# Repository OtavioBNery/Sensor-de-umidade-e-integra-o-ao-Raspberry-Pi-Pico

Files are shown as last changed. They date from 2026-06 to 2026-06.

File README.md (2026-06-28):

# Sensor-de-umidade-e-integração-ao-Raspberry-Pi-Pico
# Membros do projeto
Filipe Tadeu Chudo Sepican – 23.00563-3

Gabriela de Castro Oliveira Szwif – 23.00868-7

Otávio Biadola Nery – 23. 01584-5

João Luiz Du Plessis Lang – 22.00263-4

# Objetivo do projeto
Desenvolvimento de um sistema composto por um sensor desenvolvido pelos integrantes e pelo microcontrolador Raspberry Pi Pico que atenda ao tema de sustentabilidade, sendo escolhido trabalhar com o desenvolvimento de um sensor capacitivo de umidade do solo

# Descrição do sistema
Como pode ser visto no diagrama de blocos abaixo, o sistema consiste na leitura do valor obtido pelo sensor, sua exibição no LCD 16x2, e uma comparação com o valor da umidade percentual definida pelo usuario, de modo a gerar um controle por histerse para que atinja o valor de alvo por meio de uma lâmpada incandescente
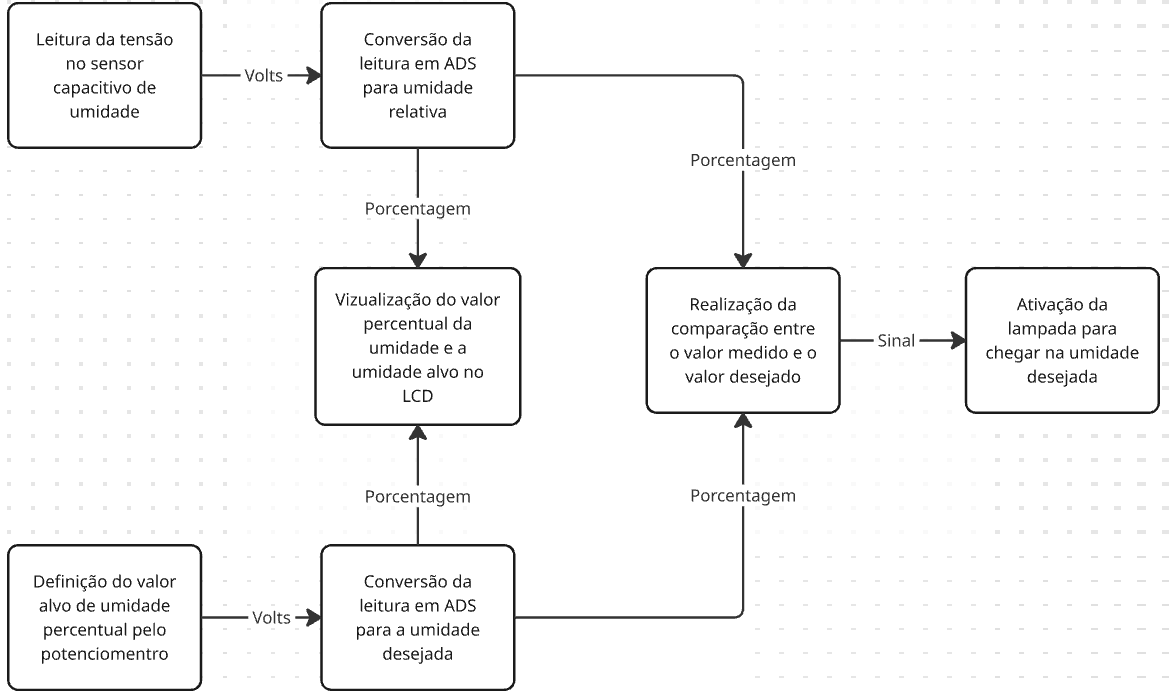
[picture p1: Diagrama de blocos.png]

<hr>

# Localização de arquivos importantes
Os arquivos de PCB, CAD, codigo do microcontrolador, apresentação do projeto e relátorio detalhado sobre o desenvolvimento da aplicação podem ser obtidos na pasta Projeto

# Sensor finalizado
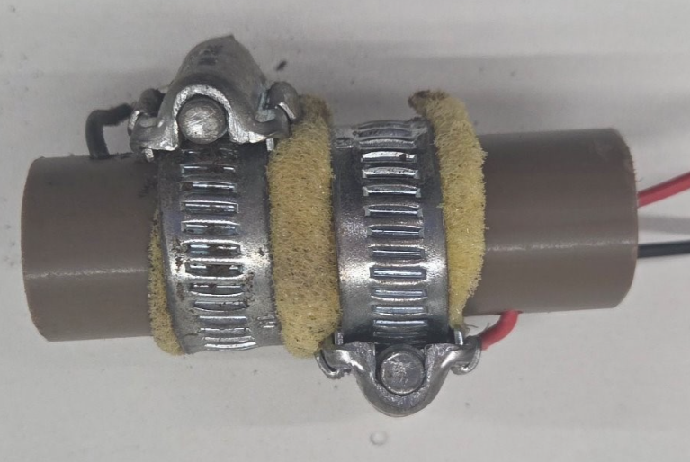
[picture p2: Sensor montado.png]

<hr>
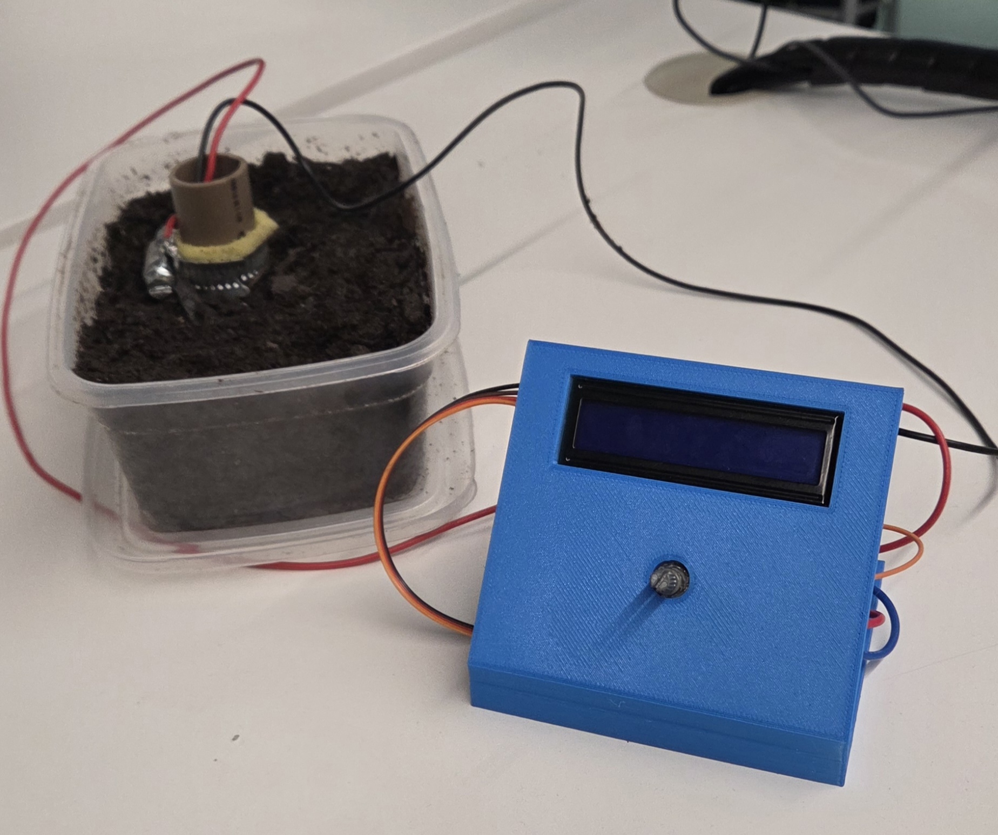
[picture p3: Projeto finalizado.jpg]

<hr>

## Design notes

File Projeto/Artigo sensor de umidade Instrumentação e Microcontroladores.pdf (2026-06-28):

Relatório do projeto semestral interdisciplinar de Instrumentação e Sistemas Microcontrolados PROJETO DA MAUÁ 2026

Filipe Tadeu Chudo Sepican 1

; Gabriela de Castro Oliveira Szwif ¹

; Otávio Biadola Nery 1
; João Luiz
Du Plessis Lang 1

; Andressa Martins 2

; Rodrigo França 2

1 Aluno(a) do Instituto Mauá de Tecnologia (IMT);
2 Professor(a) do Instituto Mauá de Tecnologia (IMT).

Resumo. O projeto consiste na confecção de um sensor capacitivo de umidade do solo integrado a um Raspberry PI Pico assim como a programação do código envolvido na leitura dos dados enviados pelo sensor, interpretação dos dados e exibição em uma tela LCD e acionamento de um relé conectado a uma lâmpada incandescente quando a umidade alvo configurada pelo usuário for atingida.

Introdução

No primeiro semestre de 2026, foi proposto um projeto integrado entre as disciplinas

Instrumentação e Microcontroladores e Sistemas Microcontrolados com o objetivo de

“[...] desenvolver competências práticas em Engenharia de Controle e Automação por meio do projeto e implementação de um sistema embarcado baseado em um sensor analógico integrado a um microcontrolados RP2040. O projeto envolve a aquisição e o condicionamento de sinais, processamento de dados, implementação de lógica de controle, comunicação e exibição de informações, além do acionamento de atuadores, aplicados a problemas reais nas áreas de saúde, automação industrial, sustentabilidade ou automação residencial.” (MARTINS; FRANÇA, 2026).

Assim, o grupo escolheu desenvolver um sensor de umidade percentual do solo, dentro do

tema de sustentabilidade. Segundo o Trabalho de Conclusão de Curso de Gustavo Neias Ribeiro

Vieira (2023), "A gestão eficiente da umidade do solo e a conservação deste recurso essencial

representam pilares fundamentais para o desenvolvimento agrícola sustentável.".

Vieira afirma, ainda, que "a agricultura necessita constantemente evoluir para atender às

demandas em constante mudança" (VIEIRA, 2023) e que o avanço tecnológico e científico "se tornou

um pilar fundamental para impulsionar a produtividade agrícola e enfrentar os desafios impostos pelas

mudanças climáticas" (VIEIRA, 2023). Ademais, o autor destaca que, dentre tais desafios, um de

grande importância é a escassez de recursos hídricos utilizáveis. Logo, o desenvolvimento de

tecnologias que tornem possível uma utilização responsável e eficiente da água é algo de extrema

importância.

Para mais, além de auxiliar na mitigação dos impactos ambientais do plantio agrícola, o

monitoramento da umidade do solo também incute em um aumento da produtividade do mesmo.

"A umidade do solo, ao influenciar o teor de ar presente, a

salinidade e a concentração de substâncias tóxicas,

desempenha um papel profundo e abrangente. Além disso, ela

está intrinsecamente conectada à estrutura do solo, à sua

espessura e à sua estabilidade. Mesmo a temperatura do solo e

sua capacidade de reter calor são impactadas pelo nível de

umidade." (VIEIRA, 2023).

Desse modo, torna-se possível adotar estratégias de otimização da produtividade a partir do

ajuste da humidade do solo. Assim, um sensor de humidade "[...] possibilita o acompanhamento em

tempo real das condições do solo, evitando desperdícios e promovendo práticas agrícolas mais

sustentáveis." (BALEEIRO et al., 2025).

Material e Métodos

Confecção do sensor

Devido as limitações propostas para o desenvolvimento do projeto, sendo primordialmente a

elaboração da aplicação sem o uso de um sensor comercial, foi decidido trabalhar com o sensor

capacitivo de umidade proposto por Barros (2020) (Figura 1) devido sua facilidade e simplicidade de

montagem e aplicação, tornando assim o projeto de fácil reprodução e com resultados consistentes.

Figura 1 – Sensor de umidade desenvolvido por Barros

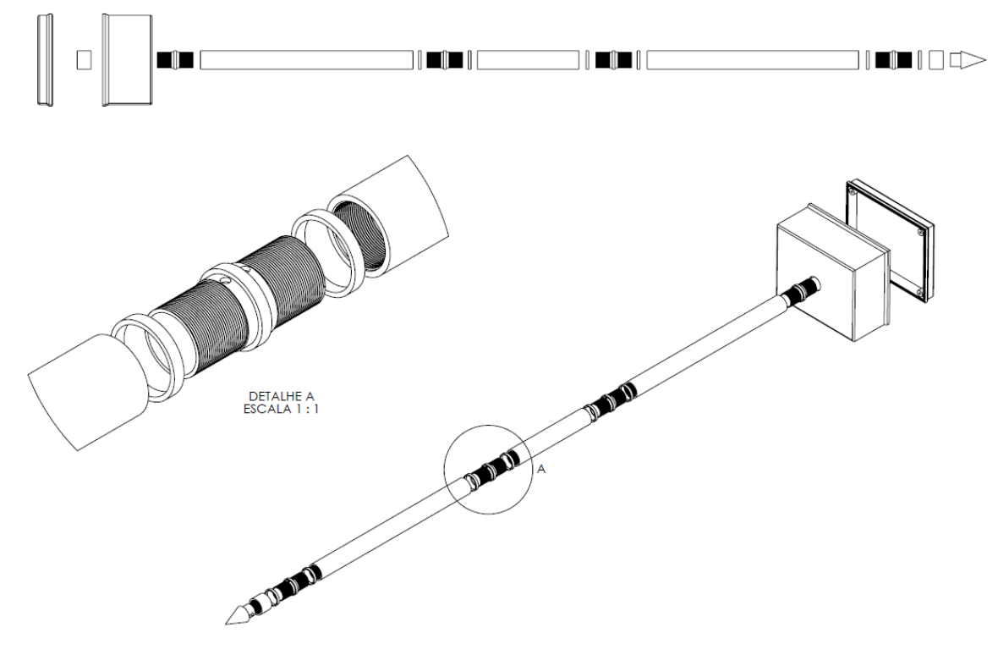
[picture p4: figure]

Fonte: Barros (2020)

Como descrito por Barros (2020, p.2), "Esse sensor consiste em duas placas paralelas feitas

de material condutor e entre elas há um material isolante chamado de dielétrico", portanto, para o

metal condutor foi escolhido trabalhar com abraçadeiras de aço inox (Figura 2) devido sua resistência

a corrosão natural, relevante considerando o ambiente em que o sensor seria instalado, e alta

resistência mecânica, garantindo assim um sensor durável ao longo prazo. Para o material dielétrico,

foi utilizado uma esponja comum de limpeza (Figura 3) devido à sua alta permeabilidade e à fácil

disponibilidade no mercado, tornando-se, assim, um projeto de fácil reprodução e mantendo um baixo

custo. Por fim, para o corpo do sensor foi selecionado um cano PVC marrom, resistente a condições

ambientais.

Figuras 2, 3 – Materiais utilizados para a confecção do sensor

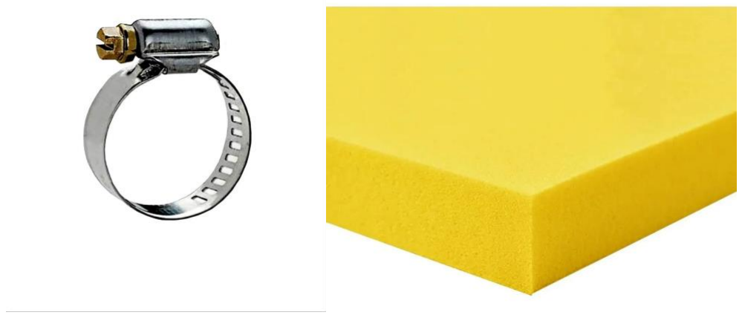
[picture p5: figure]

Fonte: Os autores

Seguindo como descrito por Barros (2020), o sensor foi desenvolvido de modo em que o

elemento dielétrico esteja em contato direto com o meio que se deseja medir, como pode ser visto na

Figura 4.

Figura 4 – Sensor de umidade finalizado

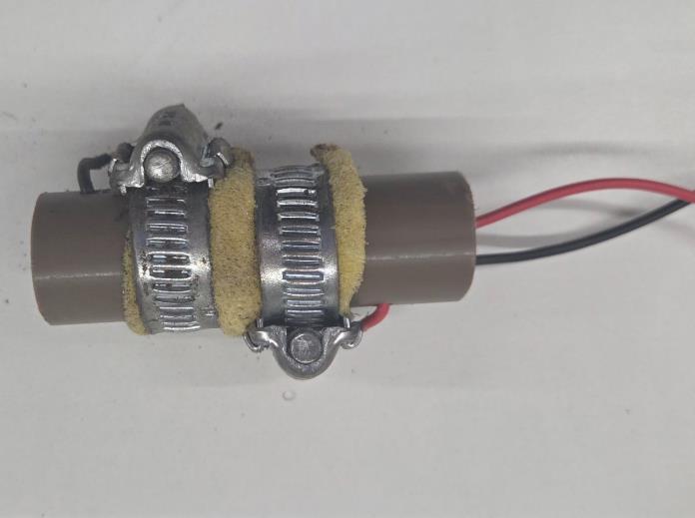
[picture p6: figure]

Fonte: Os autores

Calibração do sensor

A calibração foi feita através da determinação das tensões obtidas de dados levantados em um

ambiente controlado. Primeiramente, o sensor foi colocado em um container contendo terra seca, após

a leitura inicial, um valor inicial da carga no capacitor foi enviado ao Raspberry Pi Pico e este tornou-

se nosso valor inicial de carga nomeada “umidade do sensor em 0%”.

Após obtermos a “umidade do sensor em 0%”, água foi adicionada em steps de 5mL à terra

do container então, pulsos elétricos no intervalo de 5ms foram emitidos pelo Raspberry Pi Pico e,

com a estabilização dos valores enviados, novos pontos de umidade foram anotados. Novas medições

foram realizadas até a saturação do sensor em 35mL ser atingida.

A obtenção destes valores foi possível devido ao fato que à adição da água ao material

dielétrico muda suas propriedades capacitivas, de modo que quanto maior a quantidade de água

absorvida pelo material, menor seria seu tempo de carga completa, aumentando assim gradativamente

os valores de carga a cada adição de água no sistema até que seja atingido o valor de saturação.

Tabela 1 – Valores experimentais do ADS em relação a água inserida (mL)

Água inserida (mL) ADS
0
5 | 2500
| 2630
10 | 2810
15 | 3000
20 | 3170
25
30
35 | 3415
| 3680
| 3930

Com os valores determinados, uma equação correspondente a umidade do sensor foi traçada

e adotada para interpolação dos valores de leitura percentuais.

Projeto elétrico

Para a leitura do sinal analógico do sensor, utilizamos o microcontrolador Raspberry PI Pico,

ele foi escolhido devido ao conversor analógico para digital, ADS, já embutido no microcontrolador,

diminuindo assim a complexidade elétrica do projeto. Para a visualização e resposta do sistema, foi

empregado um display LCD 16x2 e uma lâmpada incandescente, a qual por meio de um circuito de

relé, permite um simples controle por histerese da umidade máxima desejada no sistema, sendo ela

definida pelo usuário através do uso de um potenciômetro.

Figura 6 – Esquema elétrico para leitura e resposta do sistema

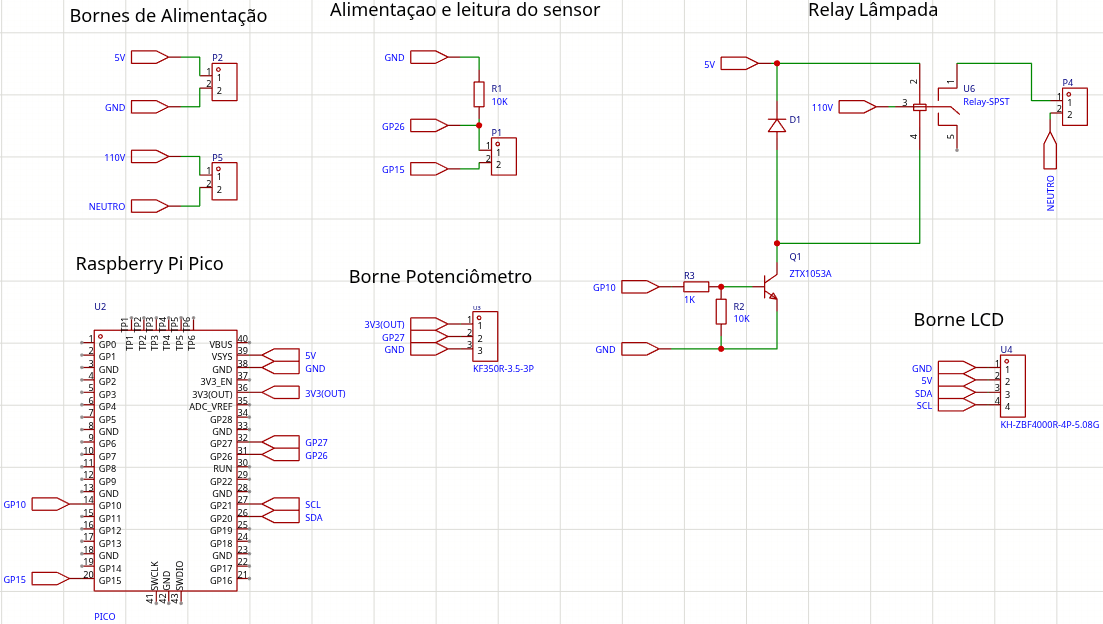
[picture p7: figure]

Fonte: Os autores

Código utilizado

Para o desenvolvimento do projeto foi utilizado programação em linguagem C devido a sua

alta velocidade e eficiência na execução dos comandos necessários. Durante a etapa da programação

do microcontrolador foram levados em consideração diversos conceitos fundamentalmente

importantes para o funcionamento adequado do sistema, dentre eles, vale se destacar: o tempo

escolhido para a carga do capacitor; a implementação de um filtro digital dos valores recebidos do

sensor; a integração da equação obtida durante o processo de calibração para converter corretamente

os valores recebidos no pino de ADS para umidade percentual; o uso de histerese para o controle do

sensor; e pôr fim a adoção de um sistema não bloqueante.

O diagrama de blocos a seguir demonstra o comportamento desejado do sistema composto

pelo sensor e o microcontrolador.

Figura 7 – Diagrama de blocos do funcionamento do sistema

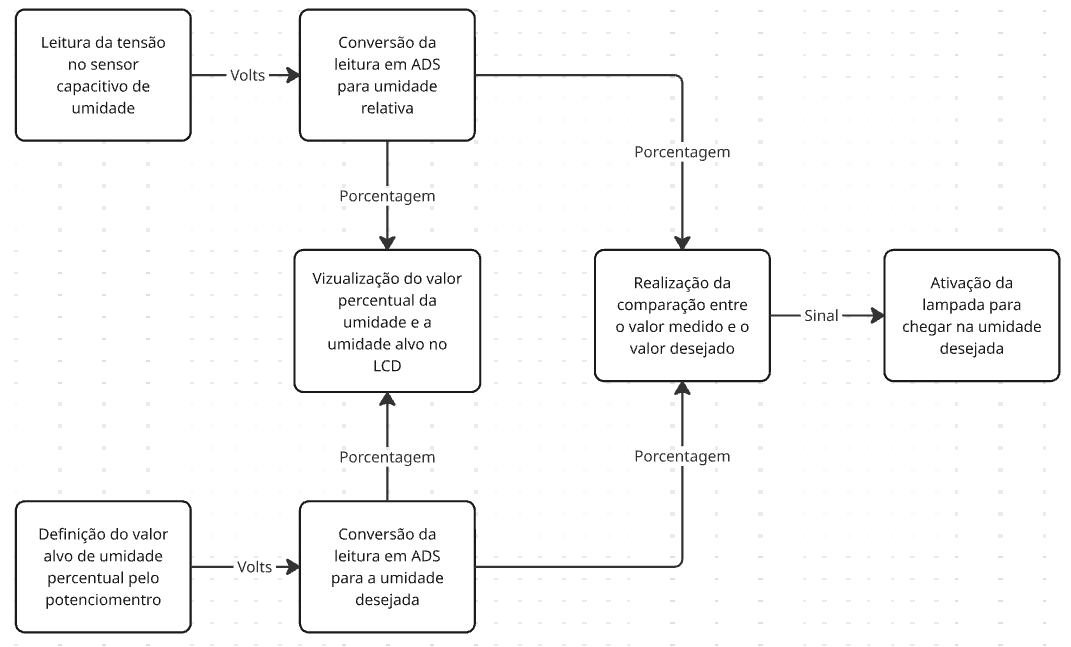
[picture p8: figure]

Fonte: Os autores
Como pode ser visto na Figura 8, há a parte do código responsável pelo tempo de carga de

1ms e a efetuação de um intervalo de 5ms entre as medidas, a qual tem o intuito de evitar uma situação

de eletrolise que danificaria as partes metálicas do sensor com o passar do tempo.

Figura 8 – Segmento do código referente ao tempo de carga e intervalo

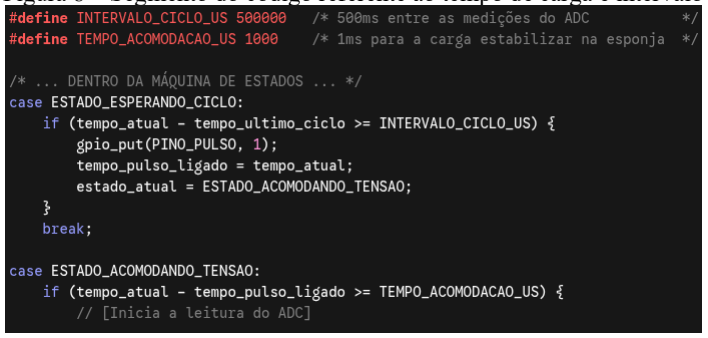
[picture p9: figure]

Fonte: Os autores
Com a intenção de diminuir o ruido no sistema, foi implementado um filtro totalmente digital,

o qual usará como entrada um conjunto de 20 medições realizadas pelo sensor antes de mudar

ativamente o valor no LCD, como pode ser visto na Figura 9.

Figura 9 – Segmento do código referente ao filtro digital utilizado

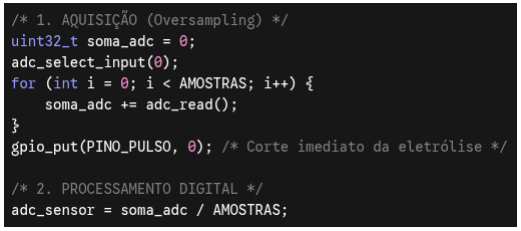
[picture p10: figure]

Fonte: Os autores
Para a realizar o controle por histerese, foi pensado que o sistema responderia à valores acima

de 5% do definido pelo usuário, evitando assim estresse desnecessário no circuito do relé e na

lâmpada incandescente.

Figura 10 – Segmento do código referente ao controle por histerese

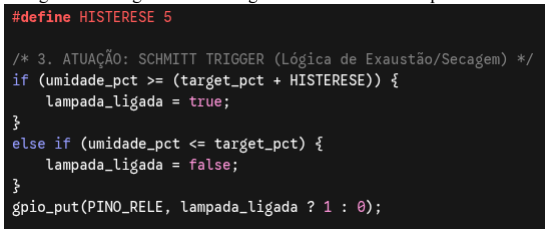
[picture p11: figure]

Fonte: Os autores
Por fim foi feita a implementação da equação de relação entre a medida ADS realizada pelo

sensor e a umidade percentual obtida durante a etapa de calibração, a fim de realizar a visualização

pelo display LCD e a comparação com o valor definido pelo usuário.

Figura 11– Segmento do código referente à implementação da equação da umidade percentual

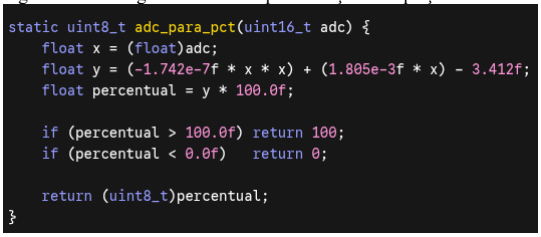
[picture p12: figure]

Fonte: Os autores

Estrutura Mecânica

Para o acomodamento do display LCD, do potenciômetro e do Raspberry PI Pico uma

estrutura em PLA foi impressa após seu modelamento em CAD (Figura 12). Na plataforma superior o LCD foi fixado através de um encaixe e o potenciômetro foi colado ao recorte projetado para seu

encaixe. O Raspberry foi acoplado a base da estrutura onde um recorte foi deixado para sua fixação.

Figura 12 – Projeto CAD da base

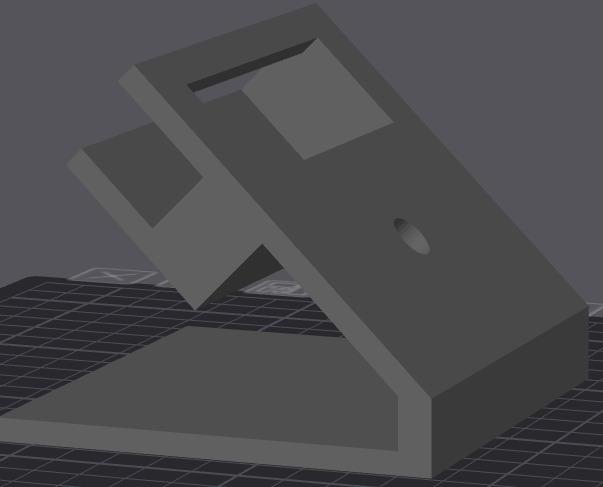
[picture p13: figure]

Fonte: Os autores

Figura 13 – Estrutura mecânica finalizada

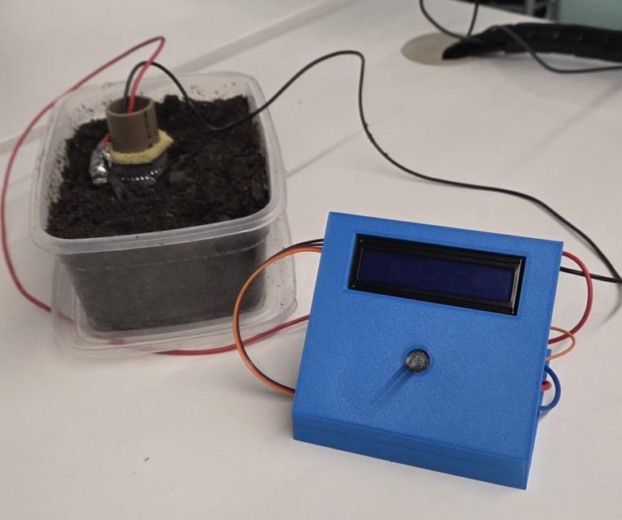
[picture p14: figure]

Fonte: Os autores

Resultados e Discussão

O sensor demonstrou alta precisão na leitura de valores da sua umidade demonstrando assim

uma curva de carga bem determinada (Figura 14). O código teve seu funcionamento ideal, não demonstrando nenhuma inconsistência e gerando a exibição correta no LCD, assim como a histerese

programada e o envio do sinal de acionamento ao relé corretamente.

Figura 14 – Curva de carga do sensor

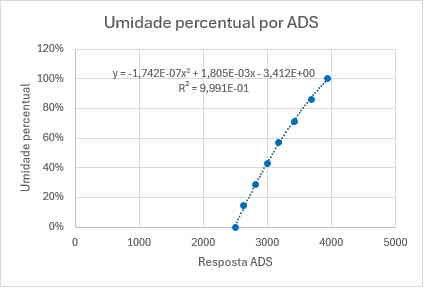
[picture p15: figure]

Fonte: Os autores

Após a conclusão do projeto certos pontos de melhora foram identificados para melhor

implementação do sensor. Primeiramente um melhor isolamento dos pontos de medida deve ser

aplicado, através de resina ou outro material isolante, tal mudança deve-se pelo fato da terra em si ser

condutiva. Em segundo lugar, o dimensionamento do resistor R1 afetou diretamente a porção

utilizada da curva do capacitor gerado pelo sensor assim, tornando-a menor e menos representativa

da umidade real. Um outro valor de resistência teria deslocado a curva suficientemente para se mostrar

mais indicativa da umidade real do ambiente e não apenas a umidade local do sensor.

No âmbito da confecção da PCB em si também houve uma falha no momento de solda do relé

e, portanto, ele não era ativado. Isso deveria ser evitado através da uma solda mais cuidadosa ou uma

PCB montada com trilhas maiores.

Conclusões

O projeto cumpriu o objetivo proposto de desenvolver as competências tanto na disciplina de

Instrumentação quanto em Sistemas Microcontrolados por meio do desenvolvimento de um sistema

embarcado para o monitoramento da umidade do solo e da integração a um sistema comandado pelo

microcontrolador RP2040. A escolha de materiais simples, como braçadeiras inox, cano PVC e

esponja comum se mostram adequadas, resultando em um sensor de baixo custo e razoavelmente

resistente as condições do ambiente de instalação, tornando assim os resultados consistentes e

previsíveis.

Como apontado na seção de resultados e discussões, melhorias como um melhor

dimensionamento do sensor e o isolamento elétrico dos componentes metálicos em contato com a terra, trariam melhorias significativas no funcionamento geral do sistema. Porém, mesmo sem tais

ajustes o sensor confeccionado cumpre o papel de uma leitura relativamente precisa da umidade local.

Referências Bibliográficas

BALEEIRO, Victor Henrique Soares; BONATTI, Matheus; MALAGOLA, Giovane Nunes; MATUNAGA, Pedro Rafael; RAMOS, Bruno Arial Ramos. (2025) Sensor de umidade do solo para
cidades | inteligentes. | Disponível | em | <
https://joins.emnuvens.com.br/joins/article/download/1329/746 >. Último acesso em: 17/06/2026.

BARROS, R. M.; COELHO, A. D.; ASSIS, W. O.; MARTINS, F. A. Desenvolvimento de Sensor de Umidade para Agricultura de Precisão. Anais do 12° Seminário Mauá de Iniciação Científica, 2020. Disponível em: https://maua.br/files/122020/desenvolvimento-sensor-umidade-para-agricultura-precisao-151455.pdf. (https://maua.br/files/122020/desenvolvimento-sensor-umidade-para-agricultura-precisao-151) Último acesso em: 26/06/2026

MARTINS, Andressa; FRANÇA, Rodrigo. (2026) Projeto Integrado das Disciplinas Instrumentação e Microcontroladores e Sistemas Microcontrolados. São Caetano do Sul.

VIEIRA, Gustavo Neias Ribeiro. (2023) Análise gravimétrica da umidade do solo e conservação para o desenvolvimento sustentável e agrícola. Trabalho de Conclusão de Curso (Curso técnico em Química). Escola Técnica Estadual Professor Carmelino Corrêa Júnior, Franca. Disponível em < https://ric.cps.sp.gov.br/handle/123456789/29346 >. Último acesso em 17/06/2026.

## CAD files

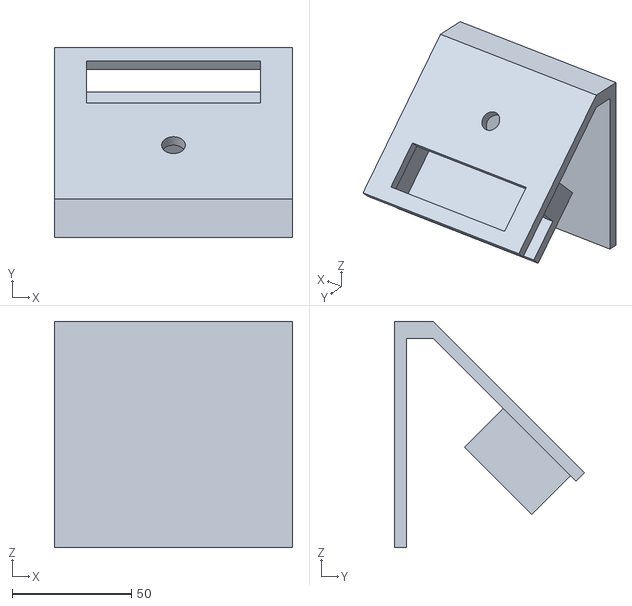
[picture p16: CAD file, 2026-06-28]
Projeto/Suporte instrumentacao.STL
100.0 x 79.8 x 95.0

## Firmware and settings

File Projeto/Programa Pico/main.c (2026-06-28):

#include <stdio.h>
#include <stdbool.h>
#include "pico/stdlib.h"
#include "hardware/adc.h"
#include "hardware/gpio.h"
#include "hardware/i2c.h"
#include "hardware/timer.h" 

/* ── MAPEAMENTO DE HARDWARE (Pinos Físicos -> GP) ──────────────────────────── */
#define PINO_SENSOR  26       /* ADC0 (Pino Físico 31) - Divisor resistivo      */
#define PINO_POT     27       /* ADC1 (Pino Físico 32) - Potenciômetro de alvo  */
#define ADC_CH_POT   1        /* Canal MUX do ADC para o GP27                   */
#define PINO_PULSO   15       /* GP15 (Pino Físico 20) - Pulso Anti-eletrólise  */
#define PINO_RELE    10       /* GP10 (Pino Físico 14) - Aciona a Lâmpada       */

/* ── DISPLAY LCD I2C (HD44780 16x2) ────────────────────────────────────────── */
#define LCD_SDA      20       /* I2C0 SDA (Pino Físico 26)                      */
#define LCD_SCL      21       /* I2C0 SCL (Pino Físico 27)                      */
#define LCD_I2C      i2c0     /* Barramento de hardware                         */
#define LCD_ADDR     0x27     /* Endereço padrão PCF8574                        */

/* ── PARÂMETROS METROLÓGICOS E TIMING ──────────────────────────────────────── */
#define AMOSTRAS           20       /* Filtro de rajada (Oversampling)          */
#define HISTERESE          5        /* Lâmpada liga apenas se Umidade >= Alvo + 5% */
#define INTERVALO_CICLO_US 500000   /* 500ms entre as medições do ADC           */
#define TEMPO_ACOMODACAO_US 1000    /* 1ms para a carga estabilizar na esponja  */

/* ── MÁQUINA DE ESTADOS (FSM) ──────────────────────────────────────────────── */
typedef enum {
    ESTADO_ESPERANDO_CICLO,
    ESTADO_ACOMODANDO_TENSAO
} EstadoSensor_t;

/* ═══════════════════════════════════════════════════════════════════════════
 * DRIVER BARE METAL: LCD HD44780
 * ═══════════════════════════════════════════════════════════════════════════ */
#define LCD_BL  (1 << 3)
#define LCD_EN  (1 << 2)
#define LCD_RS  (1 << 0)

static void lcd_write_i2c(uint8_t byte) {
    uint8_t buf = byte | LCD_BL;
    i2c_write_blocking(LCD_I2C, LCD_ADDR, &buf, 1, false);
}

static void lcd_pulse_enable(uint8_t data) {
    lcd_write_i2c(data | LCD_EN);
    sleep_us(1); 
    lcd_write_i2c(data & ~LCD_EN);
    sleep_us(50);
}

static void lcd_send(uint8_t value, uint8_t mode) {
    uint8_t high = (value & 0xF0)        | mode;
    uint8_t low  = ((value << 4) & 0xF0) | mode;
    lcd_pulse_enable(high);
    lcd_pulse_enable(low);
}

static void lcd_cmd(uint8_t cmd) { lcd_send(cmd, 0);      }
static void lcd_char(char c)     { lcd_send(c,   LCD_RS); }

static void lcd_init(void) {
    sleep_ms(50); 
    lcd_pulse_enable(0x30); sleep_ms(5);
    lcd_pulse_enable(0x30); sleep_us(150);
    lcd_pulse_enable(0x30);
    lcd_pulse_enable(0x20);  
    lcd_cmd(0x28);           
    lcd_cmd(0x0C);           
    lcd_cmd(0x06);           
    lcd_cmd(0x01);           
    sleep_ms(2);             
}

static void lcd_set_cursor(uint8_t col, uint8_t row) {
    uint8_t offsets[] = {0x00, 0x40};
    lcd_cmd(0x80 | (col + offsets[row]));
}

static void lcd_print(const char *str) {
    while (*str) lcd_char(*str++);
}

/* ═══════════════════════════════════════════════════════════════════════════
 * FUNÇÕES MATEMÁTICAS E DE CONVERSÃO
 * ═══════════════════════════════════════════════════════════════════════════ */

/* Aplica a regressão polinomial obtida do diagnóstico empírico na bancada */
static uint8_t adc_para_pct(uint16_t adc) {
    float x = (float)adc;
    
    /* 1. Cálculo da equação de calibração (saída em escala fracionária unitária) */
    float y = (-1.742e-7f * x * x) + (1.805e-3f * x) - 3.412f;

    /* 2. Ajuste de escala (Transforma a fração unitária em porcentagem bruta) */
    float percentual = y * 100.0f;

    /* 3. Clamping: Protege o sistema contra ruídos e *overflow* mecânico */
    if (percentual > 100.0f) return 100;
    if (percentual < 0.0f)   return 0;
    
    return (uint8_t)percentual;
}

/* Lê o potenciômetro e converte para degraus absolutos de 5% */
static uint8_t ler_target_pct(void) {
    adc_select_input(ADC_CH_POT);
    uint16_t raw = adc_read();                      
    uint8_t  pct = (uint8_t)((raw * 100UL) / 4095);
    pct = ((pct + 2) / 5) * 5;                     
    if (pct > 100) pct = 100;
    return pct;
}

/* ═══════════════════════════════════════════════════════════════════════════
 * LOOP DE CONTROLE (ENTRY POINT)
 * ═══════════════════════════════════════════════════════════════════════════ */
int main(void) {
    stdio_init_all();

    /* Subsistema Analógico */
    adc_init();
    adc_gpio_init(PINO_SENSOR);
    adc_gpio_init(PINO_POT);

    /* Subsistema de Potência (Transistores e Relés) */
    gpio_init(PINO_PULSO);
    gpio_set_dir(PINO_PULSO, GPIO_OUT);
    gpio_put(PINO_PULSO, 0); 

    gpio_init(PINO_RELE);
    gpio_set_dir(PINO_RELE, GPIO_OUT);
    gpio_put(PINO_RELE, 0);

    /* Inicialização I2C e Display */
    i2c_init(LCD_I2C, 100 * 1000);              
    gpio_set_function(LCD_SDA, GPIO_FUNC_I2C);
    gpio_set_function(LCD_SCL, GPIO_FUNC_I2C);
    gpio_pull_up(LCD_SDA);
    gpio_pull_up(LCD_SCL);
    lcd_init();

    printf("--- Inicializando FSM de Automacao c/ Histerese (Jay Protocol) ---\n");

    /* Variáveis da FSM e Controle de Tempo */
    uint32_t tempo_ultimo_ciclo = time_us_32();
    uint32_t tempo_pulso_ligado = 0;
    EstadoSensor_t estado_atual = ESTADO_ESPERANDO_CICLO;
    
    uint16_t adc_sensor  = 0;
    uint8_t  umidade_pct = 0;
    uint8_t  target_pct  = 0;
    
    /* Memória volátil do estado da lâmpada para operação do Schmitt Trigger */
    bool lampada_ligada = false;

    while (true) {
        uint32_t tempo_atual = time_us_32();

        switch (estado_atual) {
            
            case ESTADO_ESPERANDO_CICLO:
                if (tempo_atual - tempo_ultimo_ciclo >= INTERVALO_CICLO_US) {
                    gpio_put(PINO_PULSO, 1);
                    tempo_pulso_ligado = tempo_atual;
                    estado_atual = ESTADO_ACOMODANDO_TENSAO;
                }
                break;

            case ESTADO_ACOMODANDO_TENSAO:
                if (tempo_atual - tempo_pulso_ligado >= TEMPO_ACOMODACAO_US) {
                    
                    /* 1. AQUISIÇÃO (Oversampling) */
                    uint32_t soma_adc = 0;
                    adc_select_input(0); 
                    for (int i = 0; i < AMOSTRAS; i++) {
                        soma_adc += adc_read();
                    }
                    gpio_put(PINO_PULSO, 0); /* Corte da eletrólise */
                    
                    /* 2. PROCESSAMENTO DIGITAL */
                    adc_sensor = soma_adc / AMOSTRAS;
                    umidade_pct = adc_para_pct(adc_sensor);
                    target_pct  = ler_target_pct();

                    /* 3. ATUAÇÃO: SCHMITT TRIGGER (Lógica de Exaustão/Secagem) */
                    /* Lâmpada LIGA apenas se passar do teto (Alvo + 5%) */
                    if (umidade_pct >= (target_pct + HISTERESE)) {
                        lampada_ligada = true;
                    } 
                    /* Lâmpada DESLIGA apenas ao secar até atingir o alvo exato */
                    else if (umidade_pct <= target_pct) {
                        lampada_ligada = false;
                    }
                    /* Entre o alvo e o teto, a lâmpada preserva o estado anterior (Zona Morta) */
                    
                    gpio_put(PINO_RELE, lampada_ligada ? 1 : 0);

                    /* 4. INTERFACE HOMEM-MÁQUINA (LCD 16x2) */
                    char linha0[17], linha1[17];
                    // Formatação exata para caber em 16 colunas. %3d garante alinhamento visual
                    snprintf(linha0, sizeof(linha0), "UH: %3d%%  [%s]", umidade_pct, lampada_ligada ? "ON" : "  ");
                    snprintf(linha1, sizeof(linha1), "Alvo: %3d%%      ", target_pct);
                    
                    lcd_set_cursor(0, 0); lcd_print(linha0);
                    lcd_set_cursor(0, 1); lcd_print(linha1);

                    /* 5. TELEMETRIA UART */
                    printf("ADC: %4u | Umid: %3u%% | Alvo: %3u%% | Teto: %3u%% | Lamp: %s\n",
                           adc_sensor, umidade_pct, target_pct, (target_pct + HISTERESE), lampada_ligada ? "LIGADA" : "DESLIGADA");

                    tempo_ultimo_ciclo = tempo_atual;
                    estado_atual = ESTADO_ESPERANDO_CICLO;
                }
                break;
        }
    }

    return 0;
}

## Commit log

2026-06-28 chore: adiciona o diretório Projeto e sua estrutura de arquivos
2026-06-28 add: Arquivos relacionados ao projeto
    [Suporte instrumentacao.STL]
